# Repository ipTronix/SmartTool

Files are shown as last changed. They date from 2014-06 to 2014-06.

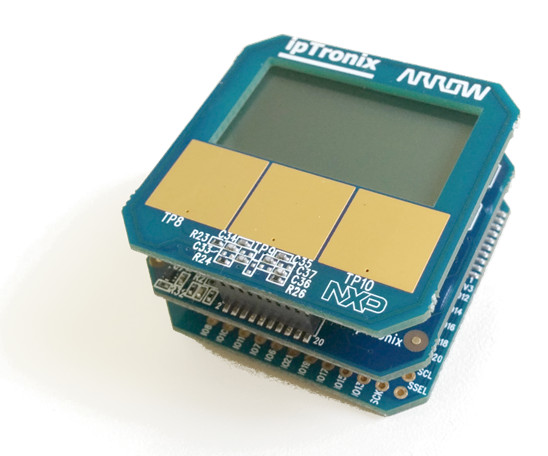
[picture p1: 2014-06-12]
Documentation/pics/SmartTool.jpg

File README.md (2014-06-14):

SmartTool
=========

SmartTool is a very compact NFC enabled microcontroller board with a 2 module wall socket form factor specifically. The addition of optional WiFi or BT modules makes the board ideal for home automation and IoT applications.

The board has been originally designed by ipTronix and financed by Arrow and NXP with the intent of spreading use of NFC technology and for this purpose a range of "production ready" applications have been developed to allow people to quickly get to a working prototype.

The software is based on FreeRTOS kernel and an embedded port of LibNFC and LibFreefare which provide a solid infrastructure for standards based communication with tags and cell phones.
Demo applications include card emulation, card reader, vending machine, authentication, data exchange with cell phone (with card emulation)

The project is completely open source and although was initially released only to customers buying the board, now it has been publicly released in full on github.

Please visit the wiki home page at http://iptronix.github.io/SmartTool/ or wiki at https://github.com/ipTronix/SmartTool/wiki to learn more

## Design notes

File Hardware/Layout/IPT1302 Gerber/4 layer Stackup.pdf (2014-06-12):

IPT1302 | | | | DIFF. 90 OHM
LAYER | DESCRIPTION | THICKNESS (um) | THICKNESS (mils) | Track–S–Track (mils) | IMP. (OHM) | DIEL. C.
coating | | 12,7 | 0,500
TOP | SIGNAL | 35 | 1,378 | 8 - 8 - 8 | 90,59 | 4,3
substrate | | 120 | 4,724
L2 | PLANE LAYER | 35 | 1,378
substrate | | 1200 | 47,244
L3 | PLANE LAYER | 35 | 1,378
substrate | | 120 | 4,724
BTM | SIGNAL | 35 | 1,378 | 8 - 8 - 8 | 90,59 | 4,3
coating | | 12,7 | 0,500
Total Thick. | 1605 | 63,205

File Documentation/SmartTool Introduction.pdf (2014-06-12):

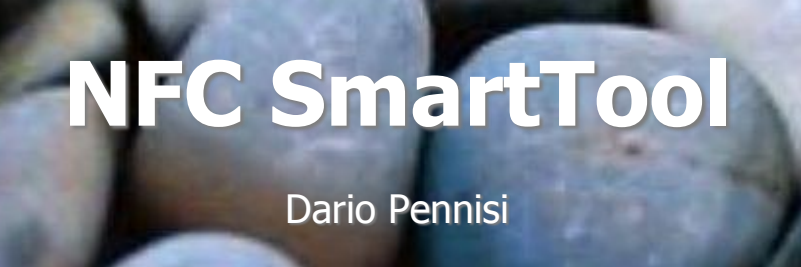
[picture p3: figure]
NFC SmartTool; Dario Pennisi
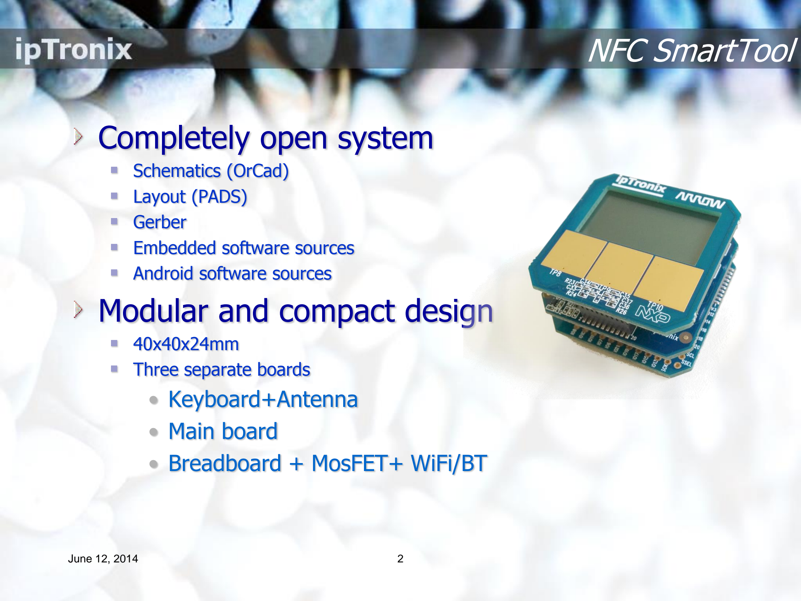
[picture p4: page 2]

NFC SmartTool

Completely open system

Schematics (OrCad)
Layout (PADS)
Gerber
Embedded software sources
Android software sources
Modular and compact design

40x40x24mm
Three separate boards
- Keyboard+Antenna
- Main board
- Breadboard + MosFET+ WiFi/BT
June 12, 2014 | 2

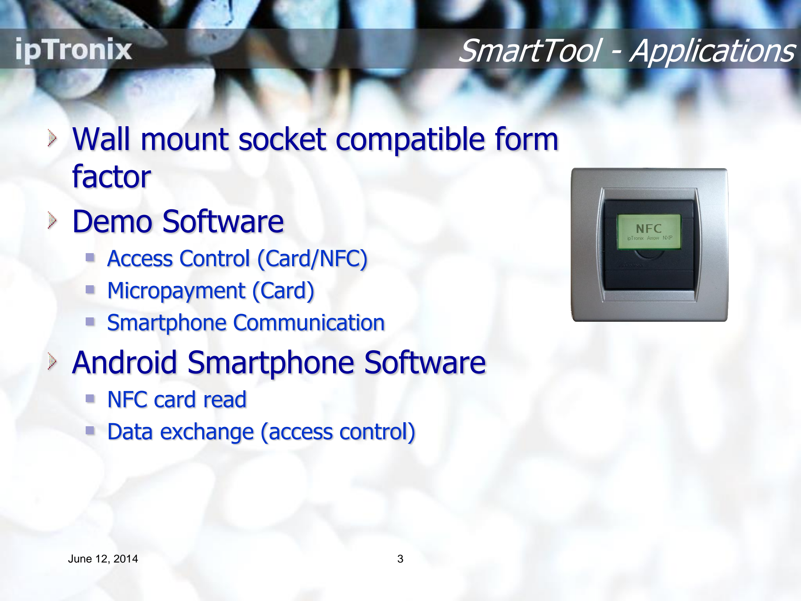
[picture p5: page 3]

SmartTool - Applications

Wall mount socket compatible form factor
Demo Software

Access Control (Card/NFC)
Micropayment (Card)
Smartphone Communication
Android Smartphone Software

NFC card read
Data exchange (access control)
June 12, 2014 | 3

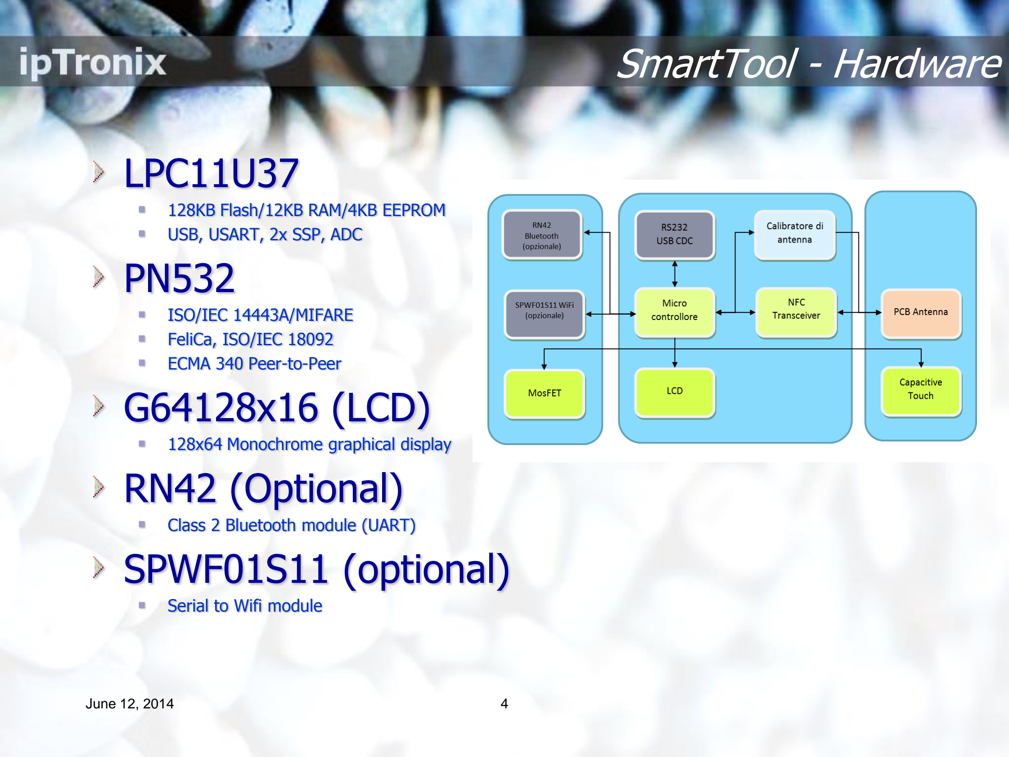
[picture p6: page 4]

SmartTool - Hardware

LPC11U37

128KB Flash/12KB RAM/4KB EEPROM USB, USART, 2x SSP, ADC
PN532

ISO/IEC 14443A/MIFARE
FeliCa, ISO/IEC 18092
ECMA 340 Peer-to-Peer
G64128x16 (LCD)

128x64 Monochrome graphical display
RN42 (Optional)

Class 2 Bluetooth module (UART)
SPWF01S11 (optional)

Serial to Wifi module

June 12, 2014 | 4

HMI

NFC
Antenna

Touch
Keys

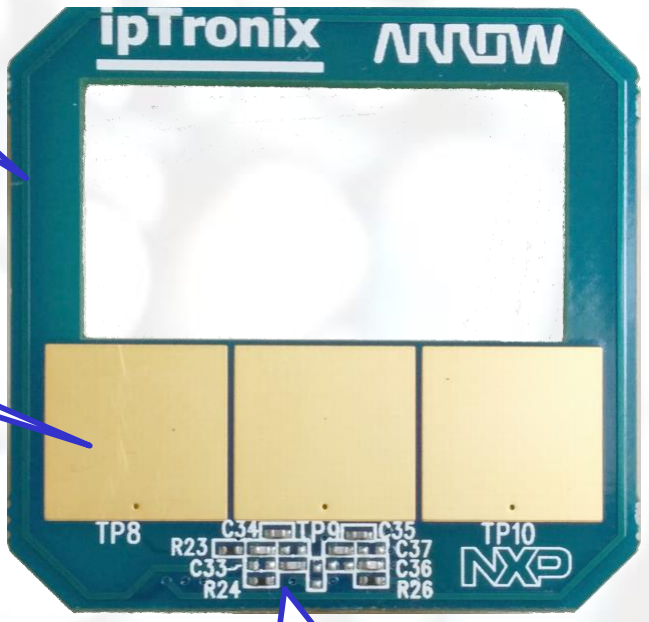
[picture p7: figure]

Antenna
Matching
network

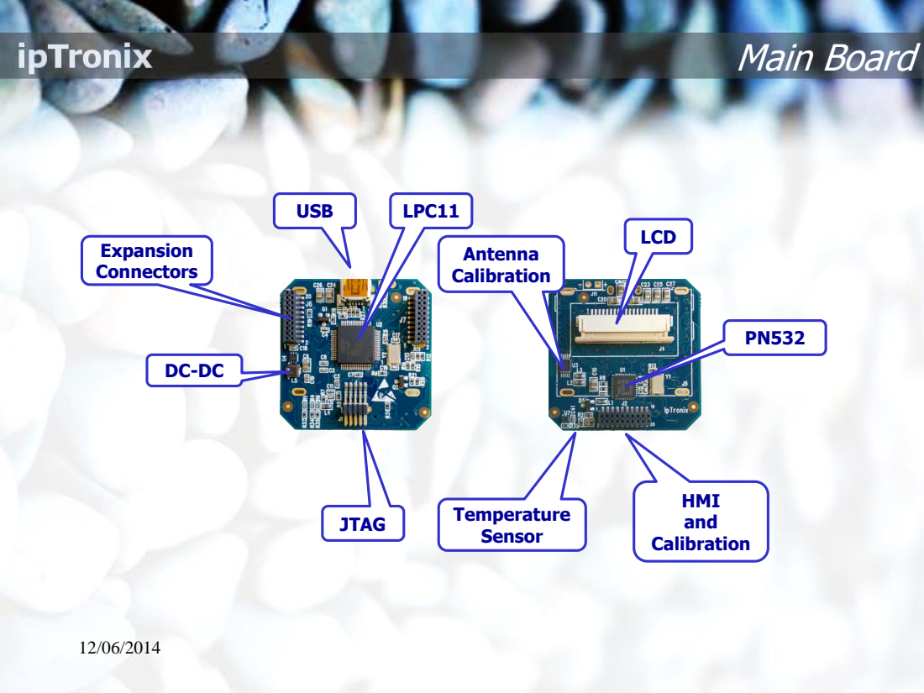
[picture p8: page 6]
Main Board; LCD; HMI and Calibration; JTAG; USB; LPC11; Expansion Connectors; Antenna Calibration; Temperature Sensor

Daughterboard

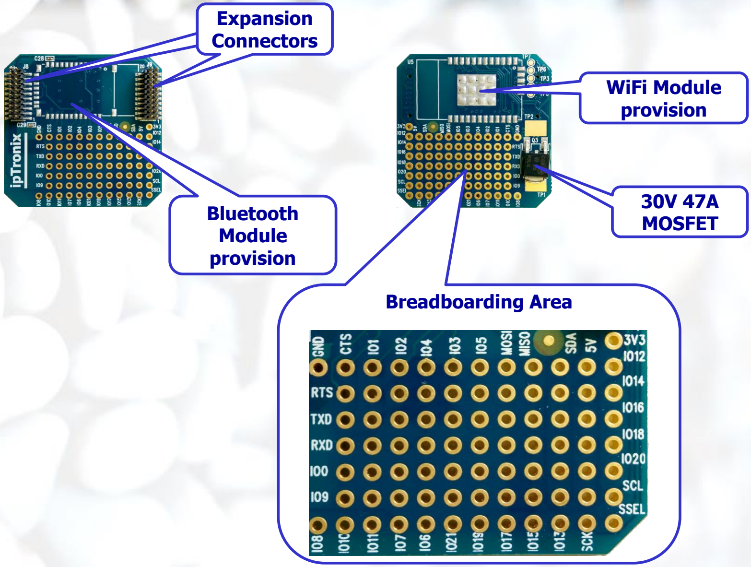
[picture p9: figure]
30V 47A MOSFET; Breadboarding Area; WiFi Module provision; Expansion Connectors; Bluetooth Module provision
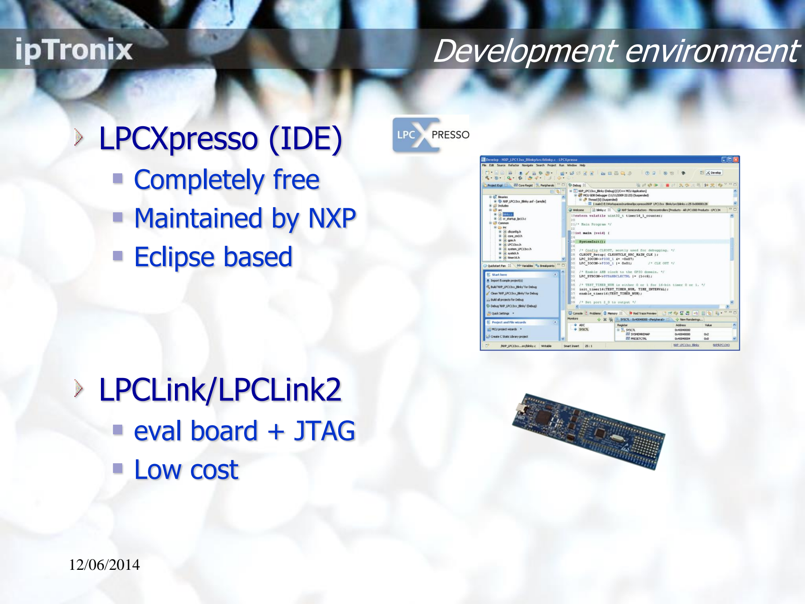
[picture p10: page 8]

Development environment

LPCXpresso (IDE)
Completely free
Maintained by NXP
Eclipse based

LPCLink/LPCLink2
eval board + JTAG
Low cost

Software - Architecture

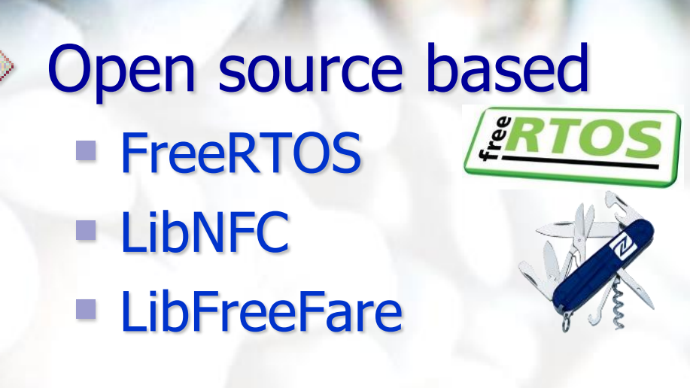
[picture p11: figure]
Open source based; FreeRTOS LibNFC LibFreeFare
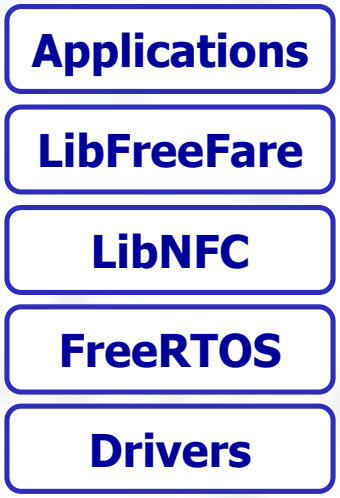
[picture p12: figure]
Drivers; FreeRTOS; LibNFC; LibFreeFare; Applications
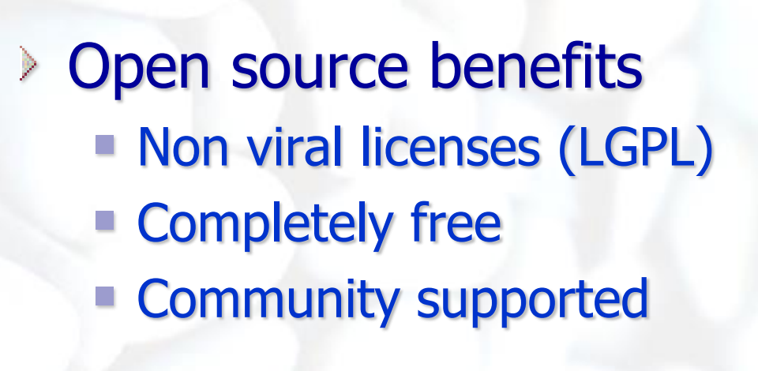
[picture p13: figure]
Open source benefits; Non viral licenses (LGPL) Completely free Community supported
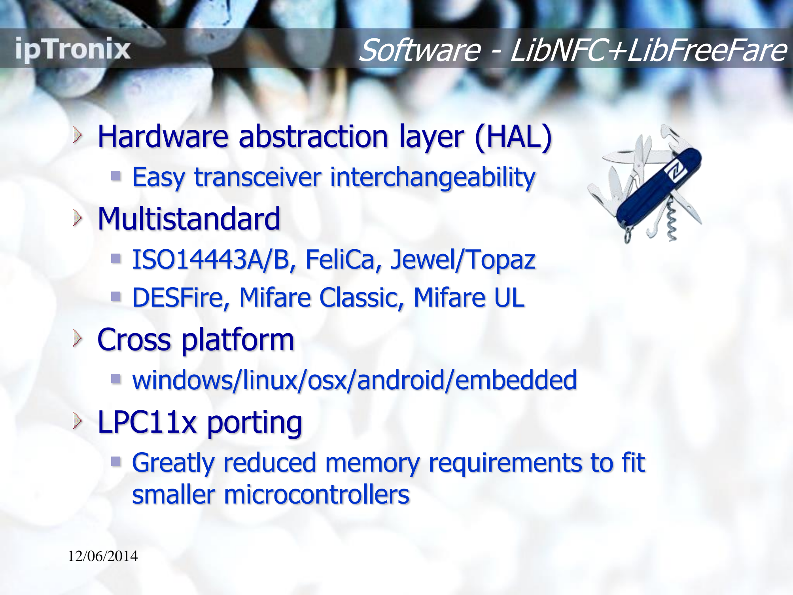
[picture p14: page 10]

Software - LibNFC+LibFreeFare

Hardware abstraction layer (HAL) Easy transceiver interchangeability Multistandard
ISO14443A/B, FeliCa, Jewel/Topaz DESFire, Mifare Classic, Mifare UL Cross platform
windows/linux/osx/android/embedded LPC11x porting
Greatly reduced memory requirements to fit smaller microcontrollers

Software - applications

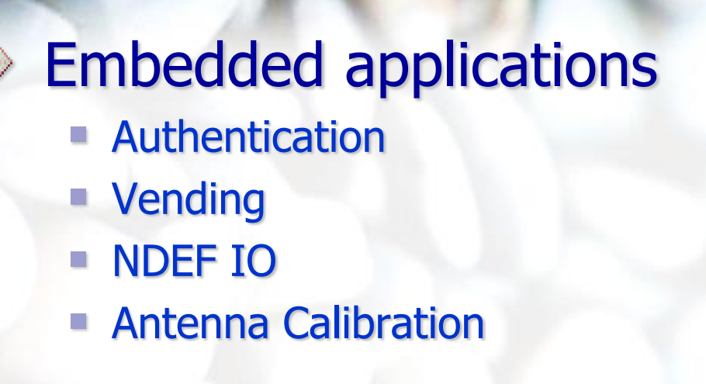
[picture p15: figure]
Embedded applications; Authentication Vending NDEF IO Antenna Calibration
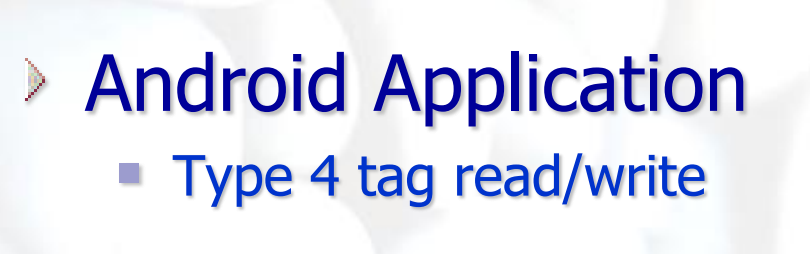
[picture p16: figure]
Android Application; Type 4 tag read/write

June 12, 2014 | 11

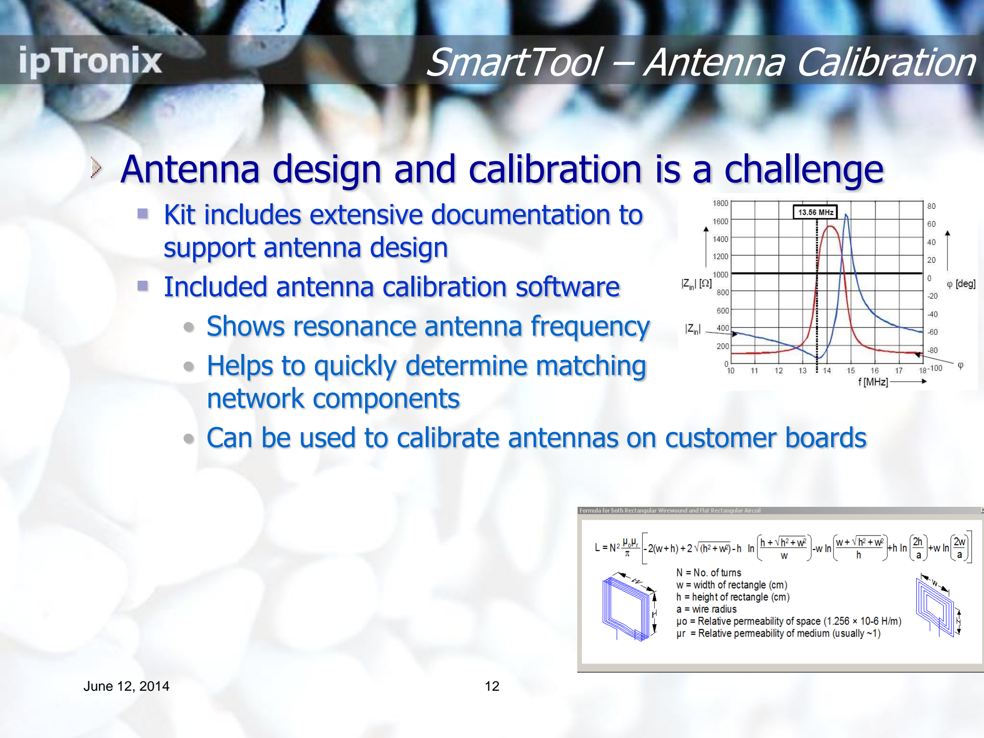
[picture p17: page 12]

SmartTool – Antenna Calibration

Antenna design and calibration is a challenge

Kit includes extensive documentation to
support antenna design
Included antenna calibration software
- Shows resonance antenna frequency
- Helps to quickly determine matching
network components
- Can be used to calibrate antennas on customer boards
June 12, 2014 | 12

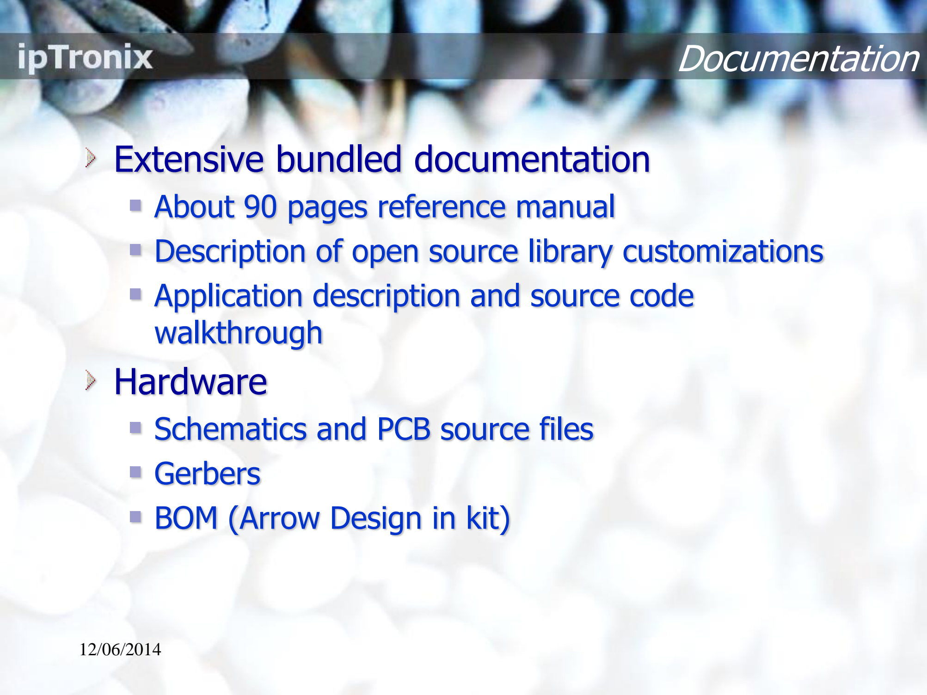
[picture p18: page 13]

Documentation

Extensive bundled documentation
About 90 pages reference manual
Description of open source library customizations Application description and source code walkthrough
Hardware
Schematics and PCB source files Gerbers
BOM (Arrow Design in kit)

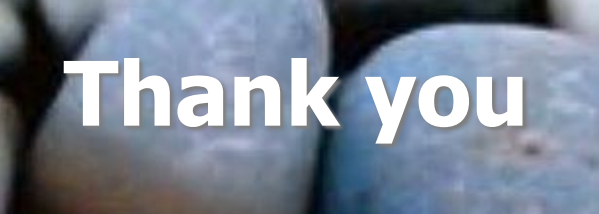
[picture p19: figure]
Thank you

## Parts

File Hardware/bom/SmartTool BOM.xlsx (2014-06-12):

Item Number | Quantity | Value | Part Reference | Manufacturer | PCB Footprint | manufacturer's part number | Case
2 | 3 | 1nF | C1 C2 C12 |  | C0402 |  | 0402
3 | 10 | 100nF | C3-C8 C11 C13 C28 C41 |  | C0402 |  | 0402
4 | 7 | 1uF | C9 C10 C23-C27 |  | C0805 |  | 0805
5 | 4 | 12pF | C14-C17 |  | C0402 |  | 0402
6 | 3 | 10uF | C18 C19 C29 | TDK | C0402 | C1005X5R0J106M050BC | 0402
7 | 4 | 4.7uF | C20-C22 C40 |  | C0805 |  | 0805
8 | 2 | 33pF | C30 C38 |  | C0402 |  | 0402
10 | 2 | 150pF | C32 C36 |  | C0402 |  | 0402
11 | 2 | 220pF COG | C34 C35 |  | C0402 |  | 0402
12 | 1 | BAT54S | D5 |  | SOT23_P123 |  | SOT23
14 | 1 | Samtec_FTSH-105-01-F-DH | J1 | Samtec | CN-FTSH-105-01-X-DH-XX-A
15 | 3 | Samtec FLE-110-01-G-DV | J2 J6 J7 | Samtec | CN-SAMTEC-FLE-110-01-X-DV
16 | 1 | Molex 51387-0530 | J3 | Molex | CN-MINIUSB-O-MLX-51387-0530
17 | 1 | Molex 0522711879 | J4 | Molex | CON_ZIF_52271-18XX
18 | 1 | CCT G64128W19BBW00 | J5 | Crystal Clear Technology ( dealer Arrow ) | DISPL_G64128X05
19 | 2 | Samtec-FTSH-110-01-F-DV | J8 J9 | Samtec | CN-SAMTEC-FTSH-110-01-F-DV
20 | 1 | Samtec FTR-110-51-G-S | J10 | Samtec | CN-SAMTEC-FLE-110-01-X-DV
22 | 4 | 0.56uH | L1-L4 | Murata | L0603 | LQM18NNR56K00D | 0603
23 | 1 | Murata LQH3NPN2R2NM0 | L5 | Murata | IND-LQH3NP-MURATA
24 | 2 | BC856 | Q1 Q2 |  | SOT23_P312 |  | SOT23
25 | 1 | BUK6213-30C | Q3 | NXP | DPAK-1S
26 | 3 | 4.7M | R1 R4 R6 |  | R0402 |  | 0402
27 | 4 | 4.7K | R2 R9 R11 R12 |  | R0402 |  | 0402
28 | 4 | 1.5K | R3 R17 R18 R22 |  | R0402 |  | 0402
29 | 2 | 1K | R5 R15 |  | R0402 |  | 0402
30 | 2 | 2K | R7 R14 |  | R0402 |  | 0402
31 | 5 | 10K | R8 R10 R13 R16 R21 |  | R0402 |  | 0402
32 | 8 | 0 | R19 R23 R24 R26 R32-R35 |  | R0402 |  | 0402
33 | 3 | 33 | R20 R27 R28 |  | R0402 |  | 0402
35 | 1 | 1M | R31 |  | R0402 |  | 0402
37 | 1 | PN5321A3HN/C106 | U1 | NXP | QFN40-6X6-P0.5 |  | HVQFN40
38 | 1 | LPC11U37FBD64/501 | U2 | NXP | QFP64-P0.5 |  | LQFP64
39 | 1 | SI5351A-B-GT | U3 | Silicon Labs | MSOP10 |  | MSOP10
40 | 1 | TPS62291 | U4 | Texas Instruments | SON6 |  | 6SON
43 | 1 | TMP112 | U7 |  | SOT563 |  | SOT563
44 | 1 | 27.12 Mhz 5032 | Y1 |  | QZS-5X3.2-SX-5032-SIWARD |  | sx5032
45 | 1 | 12 Mhz 5032 | Y2 |  | QZS-5X3.2-SX-5032-SIWARD |  | sx5032
Components not assembled ( NC = not connect / non montato )
Item Number | Quantity | Value | Part Reference | Manufacturer | PCB Footprint | manufacturer's part number | PCB Footprint
~~9~~ | ~~4~~ | ~~NC~~ | ~~C31 C33 C37 C39~~ |  | ~~C0402~~ |  | 0402
~~21~~ | ~~1~~ | ~~NC CON2 P=2,54~~ | ~~J11~~ |  | ~~ST-MV-2X1~~
~~34~~ | ~~3~~ | ~~NC 0~~ | ~~R25 R29 R30~~ |  | ~~R0402~~ |  | 0402
Notes
 |  | All capacitor voltage need to be more 3,3V except C18 that need to be more of 5V.

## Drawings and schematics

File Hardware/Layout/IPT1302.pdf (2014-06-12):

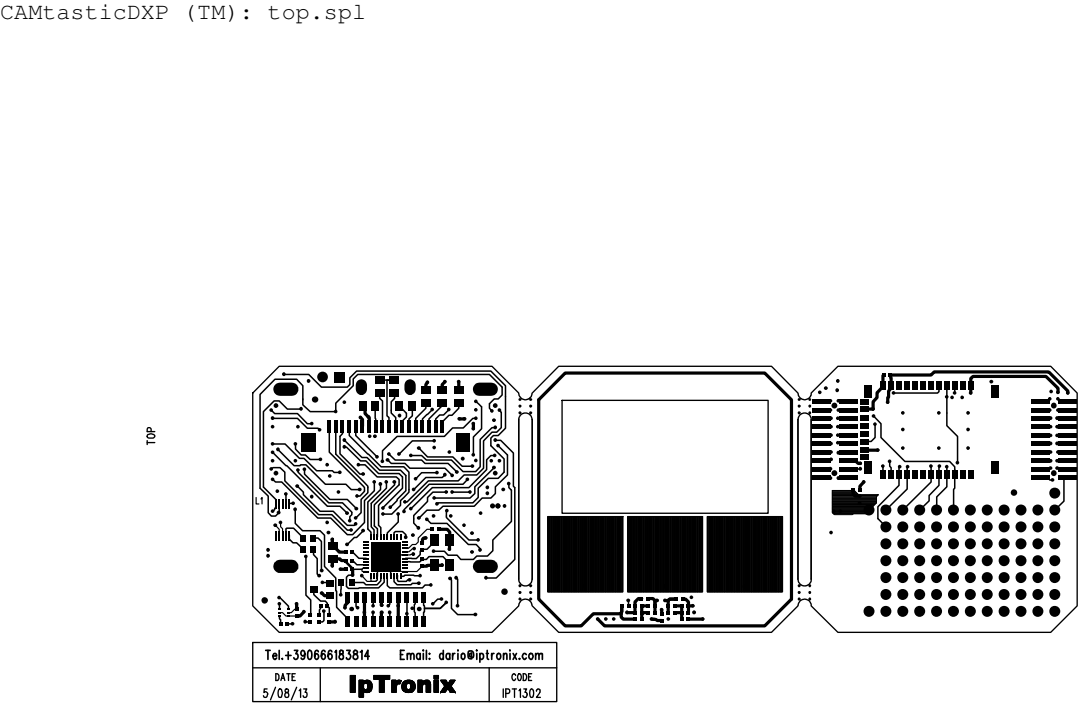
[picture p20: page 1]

CAMtasticDXP (TM): top.spl

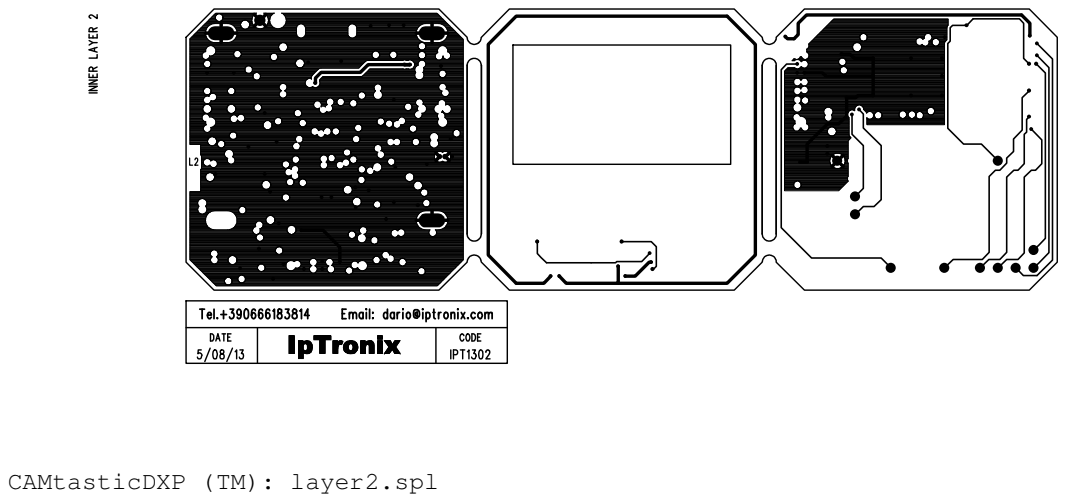
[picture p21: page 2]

CAMtasticDXP (TM): layer2.spl

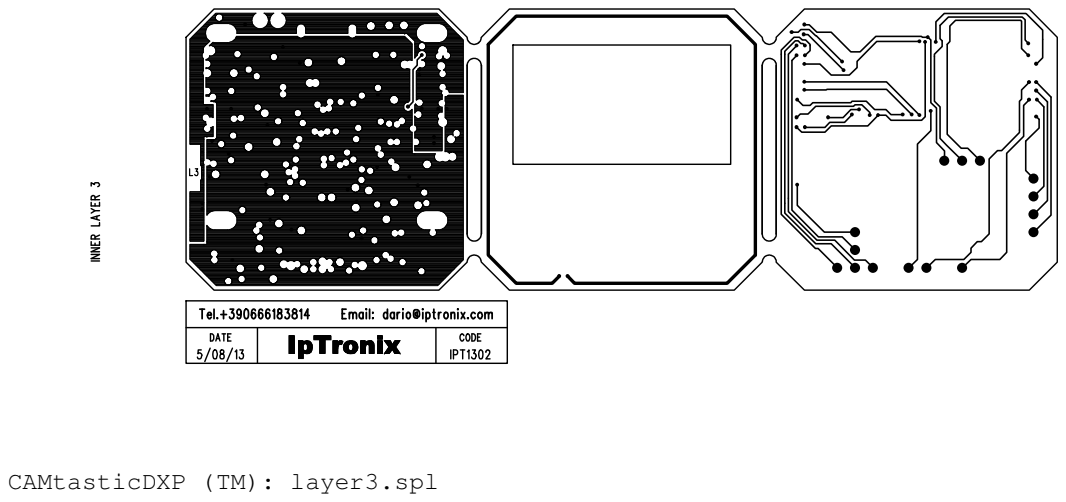
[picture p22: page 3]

CAMtasticDXP (TM): layer3.spl

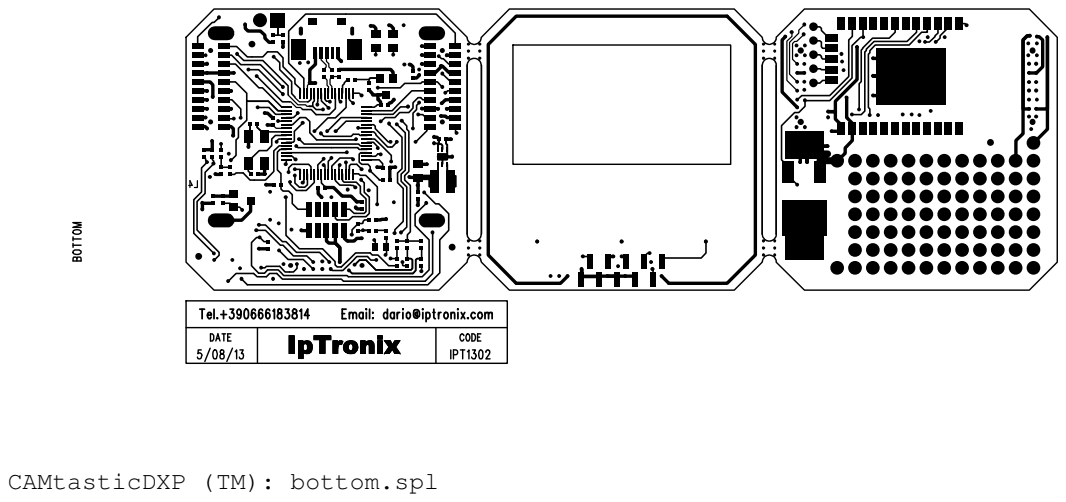
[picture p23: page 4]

CAMtasticDXP (TM): bottom.spl

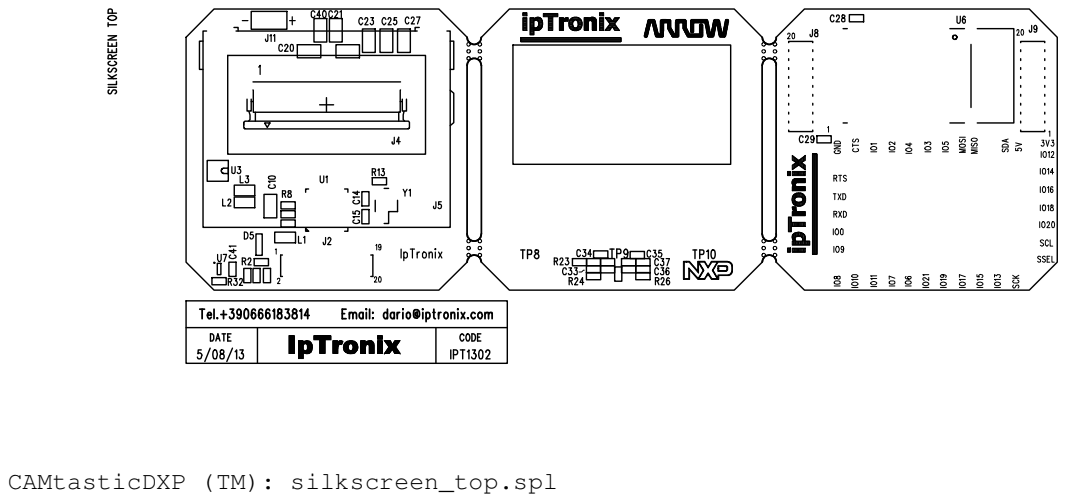
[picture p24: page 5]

CAMtasticDXP (TM): silkscreen_top.spl

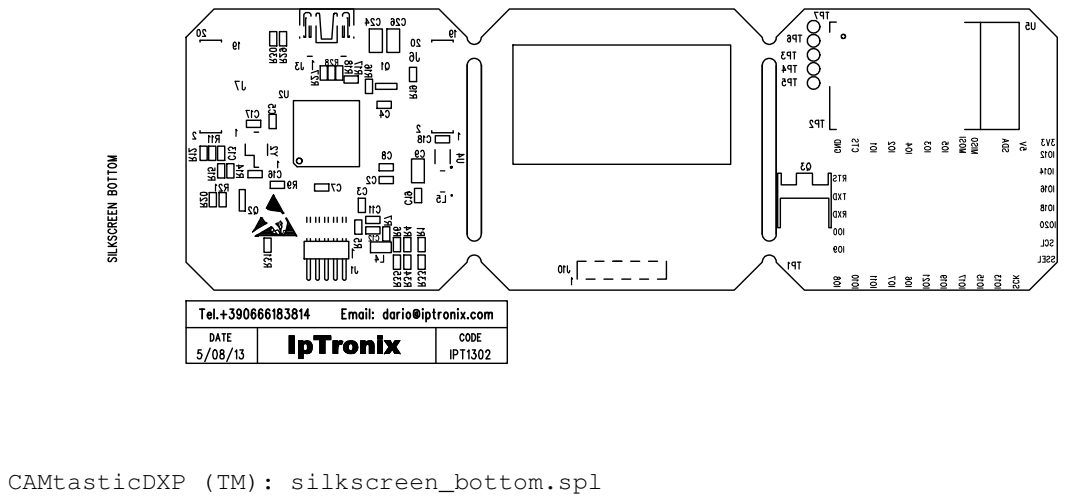
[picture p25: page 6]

CAMtasticDXP (TM): silkscreen_bottom.spl

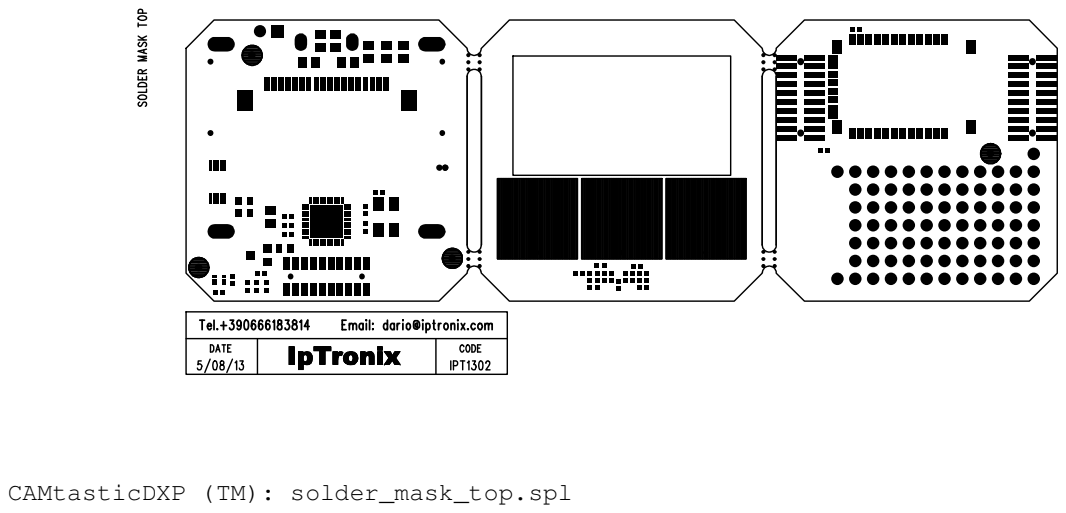
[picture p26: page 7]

CAMtasticDXP (TM): solder_mask_top.spl

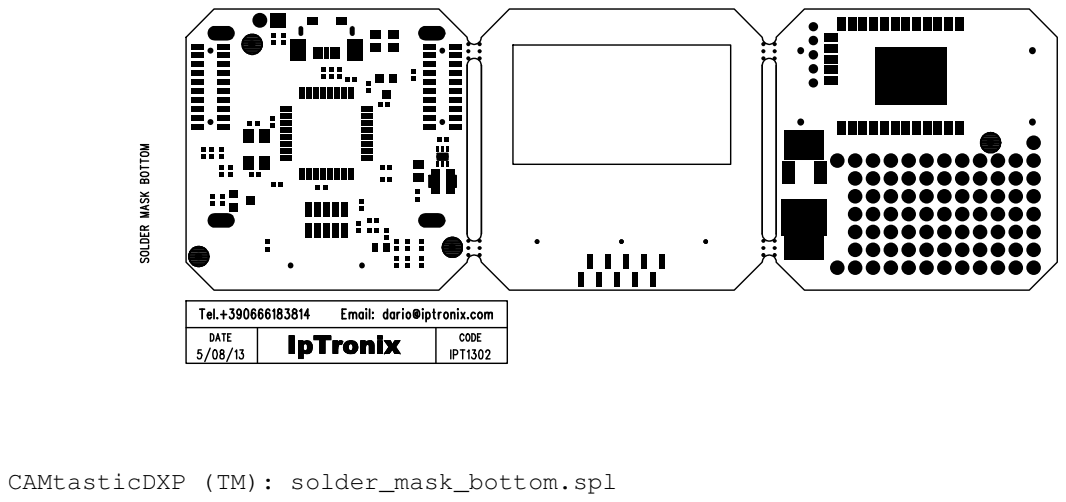
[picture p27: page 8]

CAMtasticDXP (TM): solder_mask_bottom.spl

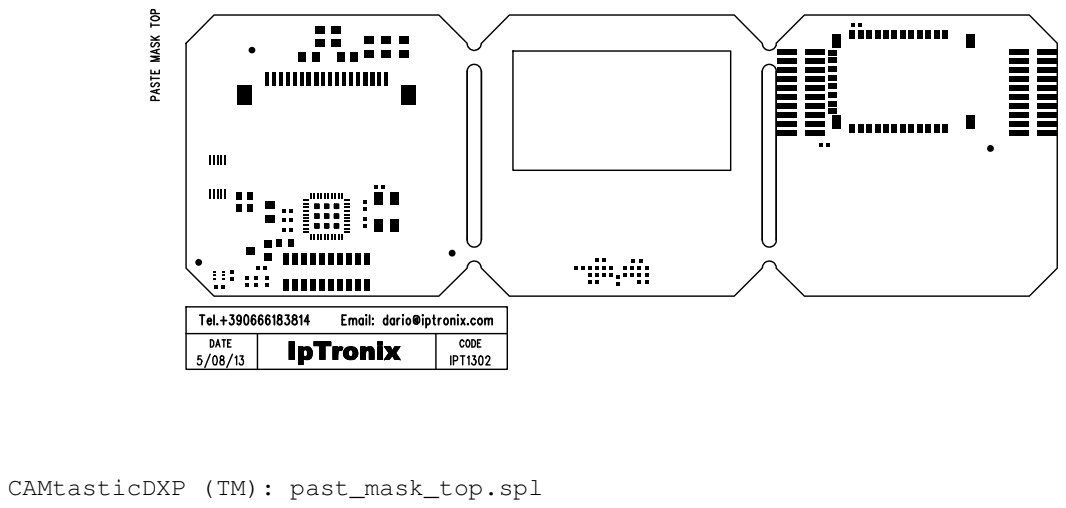
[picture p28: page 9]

CAMtasticDXP (TM): past_mask_top.spl

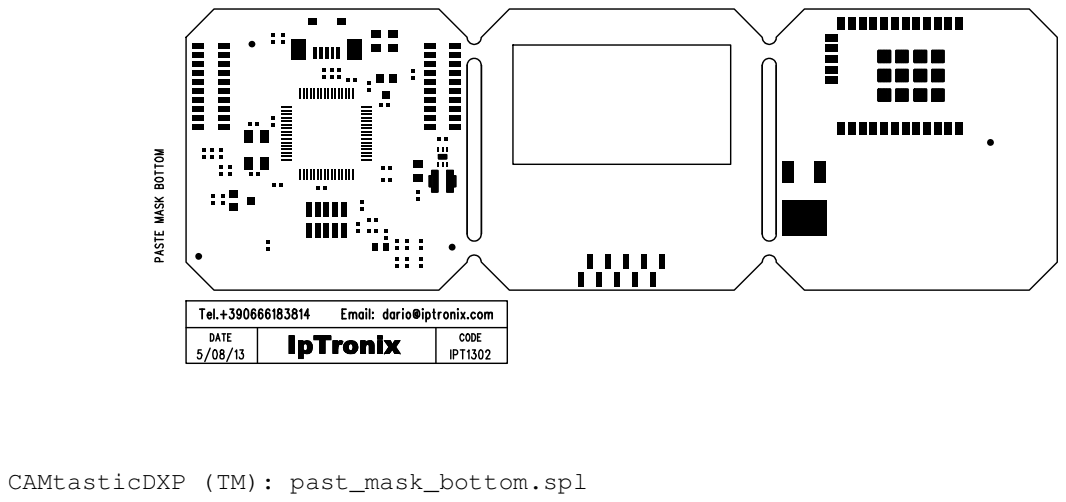
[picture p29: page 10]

CAMtasticDXP (TM): past_mask_bottom.spl

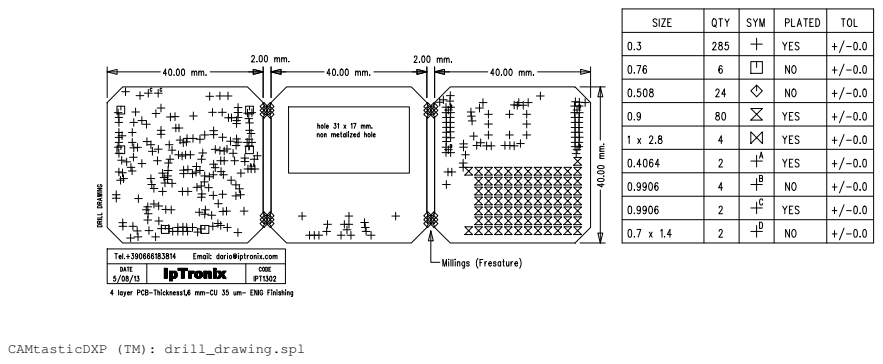
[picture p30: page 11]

CAMtasticDXP (TM): drill_drawing.spl

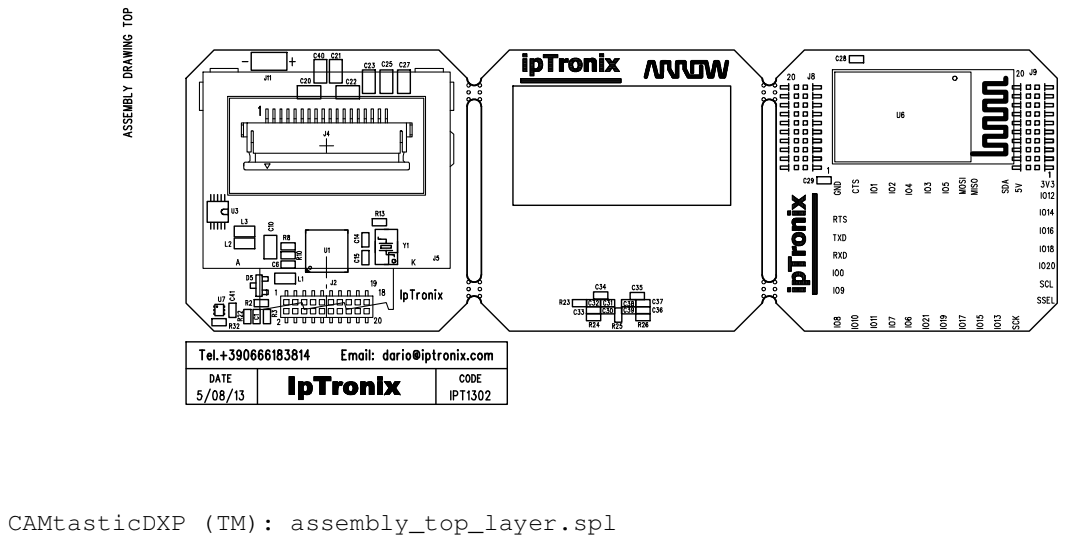
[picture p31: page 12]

CAMtasticDXP (TM): assembly_top_layer.spl


CAMtasticDXP (TM): assembly_bottom_layer.spl

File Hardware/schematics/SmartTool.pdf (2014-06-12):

D | D

# DAUGHTERCARD


REVISION 01
Il pin 9 di J4 non va collegato a massa ma piuttosto collegato fra C21 e il pin 9. aggiunto condensatore
R18 deve essere da 1.5K e deve andare verso D+, non verso USB_VBUS, inoltre andrebbero messe due
resistenze da 33 ohm in serie fra D+ e D- e il connettore
J10 diventa Samtec FTR-110-51-G-S
REVISION 01A
C32/C36 da 68pF diventa 150pF
C33/C37 da 10pF diventa NC
R1/R4/R6 da 1M diventa 4.7M
R33/R34/R35 da 1M diventa 0 ohm
REVISION 01B
Update 3D picture of BRD
update value of J11
REVISIONE 01C
change P/N Mosfer Q3 (to NXP)
REVISIONE 01D
change footrpint TP8-TP9-TP10 from PUS-TOUCH to PUS-TOUCH2
J10 footprint CN-FTS-110-01-F-SV diventa CN-SAMTEC-FLE-110-01-X-DV
J2-J6-J7 footprint CN-SAMTEC-CLP-110-02-X-D diventa CN-SAMTEC-FLE-110-01-X-DV

Arrow - NXP NFC reference desing



Human-Machine Interface (HMI) 01D


NSS 27 MOSI 28 MISO 29 SCK 30

DC-DC AND OPTIONAL EXTERNAL SUPPLY

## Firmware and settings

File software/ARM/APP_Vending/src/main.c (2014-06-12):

/*
===============================================================================
 Name        : main.c
 Author      :
 Version     :
 Copyright   : Copyright (C)
 Description : main definition
===============================================================================
*/

/* Standard includes. */
#include "string.h"

/* FreeRTOS includes. */
#include "FreeRTOS.h"
#include "task.h"

/* Hardware specific includes. */
#include "lpc11Uxx.h"
#include "SSP/ssp.h"
#include "USB_CDC/cdc.h"
#include "ADC/adc.h"
#include "I2C/i2c.h"
#include "GPIO/gpio.h"
#include "TIMER/timer16.h"
#include "TIMER/timer32.h"
#include "LCD/LCD.h"
#include "GPIO/GPIO.h"
#include "CAP_KEY/CAP_KEY.h"
#include <cr_section_macros.h>
#include <NXP/crp.h>

#include "config.h"
#include <stdio.h>

#include "FreeRTOS.h"
#include "semphr.h"

/*-----------------------------------------------------------*/

/*
 * Perform any application specific hardware configuration.  The clocks,
 * memory, etc. are configured before main() is called.
 */
static void prvSetupHardware( void );

// Variable to store CRP value in. Will be placed automatically
// by the linker when "Enable Code Read Protect" selected.
// See crp.h header for more information
__CRP const unsigned int CRP_WORD = CRP_NO_ISP ;

xQueueHandle xUIQueue = NULL;
static int32_t nAmount;
static int32_t nCardAmount;

typedef enum
{
	stIDLE,
	stSELECT,
	stVENDING,
	stRECHARGE_SEL,
	stRECHARGING,
	stSHOWCREDIT,
} STATE;

static STATE eState;
static int nCurrentItem;
static char cStateChange;
int nTransactionAmount;

#define ITEM_STR_LEN 20

typedef struct
{
	char acItem[ITEM_STR_LEN];
	int price;
} ITEM;

const ITEM asItemList[] =
{
		{ "Chips", 250},
		{ "Candy bar",100},
		{ "Water",150},
		{ "Chocolate", 300},
		{ "Ice Cream", 350}
};

#define MAX_ITEMS (sizeof(asItemList)/sizeof(ITEM))
portBASE_TYPE qres;

unsigned long command[5];
unsigned long result[4];

#define init_msdstate() *((uint32_t *)(0x10000054)) = 0x0
#define IAP_LOCATION 0x1fff1ff1
typedef void (*IAP)(unsigned long[],unsigned long[]);
IAP iap_entry = (IAP) IAP_LOCATION;

void ReinvokeISP(void)
{
  /* make sure USB clock is turned on before calling ISP */
  LPC_SYSCON->SYSAHBCLKCTRL |= 0x04000;
  /* make sure 32-bit Timer 1 is turned on before calling ISP */
  LPC_SYSCON->SYSAHBCLKCTRL |= 0x00400;
  /* make sure GPIO clock is turned on before calling ISP */
  LPC_SYSCON->SYSAHBCLKCTRL |= 0x00040;
  /* make sure IO configuration clock is turned on before calling ISP */
  LPC_SYSCON->SYSAHBCLKCTRL |= 0x10000;

  /* make sure AHB clock divider is 1:1 */
  LPC_SYSCON->SYSAHBCLKDIV = 1;

  /* Send Reinvoke ISP command to ISP entry point*/
  command[0] = 57;

  init_msdstate();                                                            /* Initialize Storage state machine */
  /* Set stack pointer to ROM value (reset default) This must be the last
     piece of code executed before calling ISP, because most C expressions
     and function returns will fail after the stack pointer is changed. */
  __set_MSP(*((uint32_t *)0x00000000));

  /* Enter ISP. We call "iap_entry" to enter ISP because the ISP entry is done
     through the same command interface as IAP. */
  iap_entry(command, result);
  // Not supposed to come back!
}

void ui_task( void * data)
{
	eState = stIDLE;
	nCurrentItem = 0;

	// init LCD;
	lcd_clear_all();
	lcd_init();
	lcd_led_power(1);
	//lcd_test(0);
	lcd_text(32,10,3,"NFC",0);
	lcd_text(12,40,1,"ipTronix   Arrow   NXP",0);
	lcd_update(0,63);

	lcd_clear_all();
	vTaskDelay(1500);
	cStateChange = 1;

	GPIOSetBitValue(PIN_MOSFET,0);
	for (;;)
	{
		char str[30];
		KEY_EVENT_t key;

		key = CAP_KEY_GetEvent();
		qres = xQueueReceive(xUIQueue,&nCardAmount,100);

		if (GPIOGetPinValue( PIN_ISP ) == 0)
		{
			lcd_clear_all();
			lcd_text(52,26,2,"ISP",0);
			lcd_update(0,63);
			NVIC_SystemReset();
		}

		if (key!=keNONE || cStateChange || qres==pdPASS)
		{
			lcd_clear_all();

			do
			{
				cStateChange = 0;
				switch (eState)
				{
					case stIDLE:
					{
						if (key==keK1_PRESS)
						{
							eState = stSELECT;
							cStateChange = 1;
							nCurrentItem = 0;
						}
						else if (key==keK3_PRESS)
						{
							eState = stRECHARGE_SEL;
							cStateChange = 1;
						}
						else
						{
							lcd_text(32,0,1,"Vending Demo",0);
							lcd_text(12,20,2,"Select function",0);
							lcd_text( 0,52,2,"   Buy   ",1);
							lcd_text(75,52,2," Charge ",1);
						}
					}
					break;
					case stSELECT:
					{
						if (key==keK2_PRESS)
						{
							eState=stVENDING;
							nTransactionAmount = -asItemList[nCurrentItem].price;
							cStateChange=1;
						}
						else
						{
							if ((key==keK1_PRESS || key==keK1_REPEAT)&& nCurrentItem>0)
								nCurrentItem--;
							else if ((key==keK3_PRESS || key==keK3_REPEAT)&& nCurrentItem<(MAX_ITEMS-1))
								nCurrentItem++;
							{
								lcd_text(22,0,2," select item",0);
								lcd_text( 0,52,1,"   /\\   ",1);
								lcd_text(40,52,1,"   Select   ",1);
								lcd_text(100,52,1,"   \\/   ",1);
								for (int i=0;i<3;i++)
								{
									if ((i+nCurrentItem)>0 && (i+nCurrentItem)<=MAX_ITEMS)
									{
										sprintf(str,
												    "%2d.%02d",
														asItemList[i-1+nCurrentItem].price/100,
														asItemList[i-1+nCurrentItem].price%100);
										lcd_text(12, 13*(i+1),2,asItemList[i-1+nCurrentItem].acItem,0);
										lcd_text(90, 13*(i+1),2,str,0);
									}
								}
								lcd_invert_area(0,13*2,127,13*3);
							}
						}
					}
					break;
					case stVENDING:
					{
						if (key==keK1_PRESS)
						{
							eState=stIDLE;
							cStateChange=1;
							nTransactionAmount = 0;
						}
						else if (qres==pdPASS)
						{
							eState=stSHOWCREDIT;
							cStateChange=1;
						}
						else
						{
							lcd_text(32,20,2,"Scan Card",0);
							lcd_text( 0,52,1,"Cancel",1);
						}
					}
					break;
					case stRECHARGE_SEL:
					{
						if (key==keK2_PRESS)
						{
							eState=stRECHARGING;
							cStateChange = 1;
							nTransactionAmount = nAmount;
						}
						else
						{
							if ((key==keK1_PRESS || key==keK1_REPEAT)&& nAmount<1000)
								nAmount+=10;
							else if ((key==keK3_PRESS || key==keK3_REPEAT)&& nAmount>0)
								nAmount-=10;
							sprintf(str,"%2d.%02d",nAmount/100,nAmount%100);
							lcd_text(12,0,2,"Select amount",0);
							lcd_text(12,15,3,str,0);
							lcd_text( 0,52,1,"   /\\   ",1);
							lcd_text(40,52,1,"   Select   ",1);
							lcd_text(100,52,1,"   \\/   ",1);
						}
					}
					break;
					case stRECHARGING:
					{
						if (key==keK1_PRESS)
						{
							eState=stIDLE;
							cStateChange=1;
							nTransactionAmount = 0;
							key = keNONE;
						}
						else if (qres==pdPASS)
						{
							eState=stSHOWCREDIT;
							cStateChange=1;
						}
						else
						{
							lcd_text(32,20,2,"Scan Card",0);
							lcd_text( 0,52,1,"Cancel",1);
						}
					}
					break;
					case stSHOWCREDIT:
					{

						if (nCardAmount <0)
						{
							nCardAmount = -nCardAmount;
							lcd_text(0,0,2,"Not enough Credit:",0);
						}
						else
						{
							lcd_text(12,0,2,"Credit:",0);
						}
						sprintf(str,"%d.%02d",nCardAmount/100,nCardAmount%100);
						lcd_text(12,12,3,str,0);
						lcd_update(0,63);
						vTaskDelay(2000);
						GPIOSetBitValue(PIN_MOSFET,0);
						eState=stIDLE;
						cStateChange=1;
						lcd_clear_all();
					}
					break;
				}
				key = keNONE;
			} while (cStateChange);
			lcd_update(0,63);
		}

	}

}

void nfc_task( void * data);

int main(void) {

	if (GPIOGetPinValue( PIN_ISP ) == 0)
	{
		ReinvokeISP();
	}
	/* Prepare the hardware to run this demo. */
	prvSetupHardware();

	nTransactionAmount = 0;

	xTaskCreate(ui_task,                                /* The function that implements the task. */
				( signed char * ) "UI",                 /* The text name assigned to the task - for debug only as it is not used by the kernel. */
				200,                                    /* The size of the stack to allocate to the task. */
				NULL,                                   /* The parameter passed to the task - just to check the functionality. */
				tskIDLE_PRIORITY,                       /* The priority assigned to the task. */
				NULL );
	xTaskCreate(nfc_task,                                /* The function that implements the task. */
				( signed char * ) "NFC",                /* The text name assigned to the task - for debug only as it is not used by the kernel. */
				500,                                    /* The size of the stack to allocate to the task. */
				NULL,                                   /* The parameter passed to the task - just to check the functionality. */
				tskIDLE_PRIORITY,                       /* The priority assigned to the task. */
				NULL );
	xUIQueue = xQueueCreate(1,sizeof(int32_t));

	/* Start the tasks and timer running. */
	vTaskStartScheduler();

	/* If all is well, the scheduler will now be running, and the following
	line will never be reached.  If the following line does execute, then
	there was insufficient FreeRTOS heap memory available for the idle and/or
	timer tasks	to be created.  See the memory management section on the
	FreeRTOS web site for more details. */
	for( ;; );
}

static void prvSetupHardware( void )
{


	SystemCoreClockUpdate();

    // enable clock to RAM1
	LPC_SYSCON->SYSAHBCLKCTRL |= (1<<26);

	// init GPIO
	GPIOInit();

	// init I2C
	I2CInit(I2CMASTER);

	//init ADC
	ADCInit(ADC_CLK);

	// init SPI ports
	SSP_IOConfig( 0 );
	SSP_Init( 0 );
	SSP_IOConfig( 1 );
	SSP_Init( 1 );

	// init keyboard
	CAP_KEY_Init();

	// init MOSFET pin
	LPC_IOCON->PIO1_25=0x90;
	GPIOSetDir(PIN_MOSFET,1);

}
/*-----------------------------------------------------------*/

void vApplicationMallocFailedHook( void )
{
	/* vApplicationMallocFailedHook() will only be called if
	configUSE_MALLOC_FAILED_HOOK is set to 1 in FreeRTOSConfig.h.  It is a hook
	function that will get called if a call to pvPortMalloc() fails.
	pvPortMalloc() is called internally by the kernel whenever a task, queue,
	timer or semaphore is created.  It is also called by various parts of the
	demo application.  If heap_1.c or heap_2.c are used, then the size of the
	heap available to pvPortMalloc() is defined by configTOTAL_HEAP_SIZE in
	FreeRTOSConfig.h, and the xPortGetFreeHeapSize() API function can be used
	to query the size of free heap space that remains (although it does not
	provide information on how the remaining heap might be fragmented). */
	taskDISABLE_INTERRUPTS();
	for( ;; );
}
/*-----------------------------------------------------------*/

void vApplicationStackOverflowHook( xTaskHandle pxTask, signed char *pcTaskName )
{
	( void ) pcTaskName;
	( void ) pxTask;

	/* Run time stack overflow checking is performed if
	configCHECK_FOR_STACK_OVERFLOW is defined to 1 or 2.  This hook
	function is called if a stack overflow is detected. */
	taskDISABLE_INTERRUPTS();
	for( ;; );
}
/*-----------------------------------------------------------*/

void vApplicationIdleHook( void )
{
	__WFI();
}

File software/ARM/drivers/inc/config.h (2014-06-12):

/*
 * config.h
 *
 *  Created on: 27 Jun 2013
 *      Author: Dario Pennisi
 */

#ifndef CONFIG_H_
#define CONFIG_H_


//libfnc defines
#define PACKAGE_VERSION 0
#define DRIVER_PN532_SPI_ENABLED
#define NFC_STATIC_STRUCTS
//#define LOG
#define PRIuPTR "08x"
#define PRIu32  "08x"
#define PRINTF_MAX_DELAY 1
#define NFC_POLL_TIMEOUT 1000

// libfreefare specific defines
#define LITTLE_ENDIAN 1234
#define BIG_ENDIAN 4321
#define bswap_16(x) __REV16(x)
#define CFSwapInt32LittleToHost(x) x
#define CFSwapInt32HostToLittle(x) x
#define CFSwapInt32BigToHost(x) __REV(x)
#define CFSwapInt32HostToBig(x) __REV(x)
#define BYTE_ORDER LITTLE_ENDIAN

#define CAPKEY_QSIZE 3
#define UART_BUFSIZE         0x40

// hardware specific defines
#define LCD_SPI_PORT 1
#define PN532_SPI_PORT 0

// SSP configuration
#define USE_CS 0
#define SSP0_CLK_P1_29 1

// set spi1 clk to pin P1_15 for LCD
//#define SSP1_CLK_P1_20 1
#define SSP1_CLK_P1_15 1

// MISO is not used
//#define SSP1_MISO_P1_21 1
//#define SSP1_MISO_P0_22 1

// set spi1 MISO to pin P0_21 for LCD
//#define SSP1_MOSI_P1_22 1
#define SSP1_MOSI_P0_21 1

// set spi1 CS to pin P1_19 for LCD
//#define SSP1_CS_P1_23 1
#ifdef HW_REV1
#define SSP1_CS_P1_19 1
#else
#define SSP1_CS_P0_13 1
#endif

// PIN definition
#define PIN_KEY_COMMON  PORT0, 20
#define PIN_LCD_CD		PORT1, 7
#define PIN_LCD_RESET	PORT1, 6
#define PIN_LCD_LED		PORT0, 11
#define PIN_NFC_IRQ		PORT0,16
#define PIN_MOSFET		PORT1,25
#define PIN_CAL_DET		PORT1,27
#define PIN_ISP			PORT0,7

#endif /* CONFIG_H_ */
